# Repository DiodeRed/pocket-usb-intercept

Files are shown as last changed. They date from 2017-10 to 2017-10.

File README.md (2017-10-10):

# pocket-usb-intercept
A small mod board for the GDP Pocket to add a tiny internal USB hub for various purposes.

#### Bill of materials:

| Reference | Description | Part Number |
|---|---|---|
| U1 | 4-port USB 2.0 Hub IC | CY7C65632-28LTXC |
| Y1 | 12MHz Crystal | ABM10-166-12.000MHZ-T3 |
| R4 | 649 resistor (0603, 1%) | (generic) |
| R1,R3 | 10k resistor (0603, 1%) | (generic) |
| R2 | 47k resistor (0603, 1%) | (generic) |
| C3,C4 | 7pF capacitor (0603, 50V, NP0) | CGA3E2NP01H070D080AA |
| C5 | 1uF capacitor (0603, 25V, X7R) | CL10B105KA8NNNC |
| C1,C2 | 10uF capacitor (0805, 6.3V, X5R, low profile) | CL21A106MQCLNNC |
| P1,P2 | Flat Flex Connector | FH19C-10S-0.5SH |
| | 10pos 0.5mm pitch 4cm Flex Cable | 152660095 |
| | PCB (16mm x 13mm x 0.4mm) | |

---

<br />This work is licensed under a <a rel="license" href="http://creativecommons.org/licenses/by-sa/4.0/">Creative Commons Attribution-ShareAlike 4.0 International License</a>.

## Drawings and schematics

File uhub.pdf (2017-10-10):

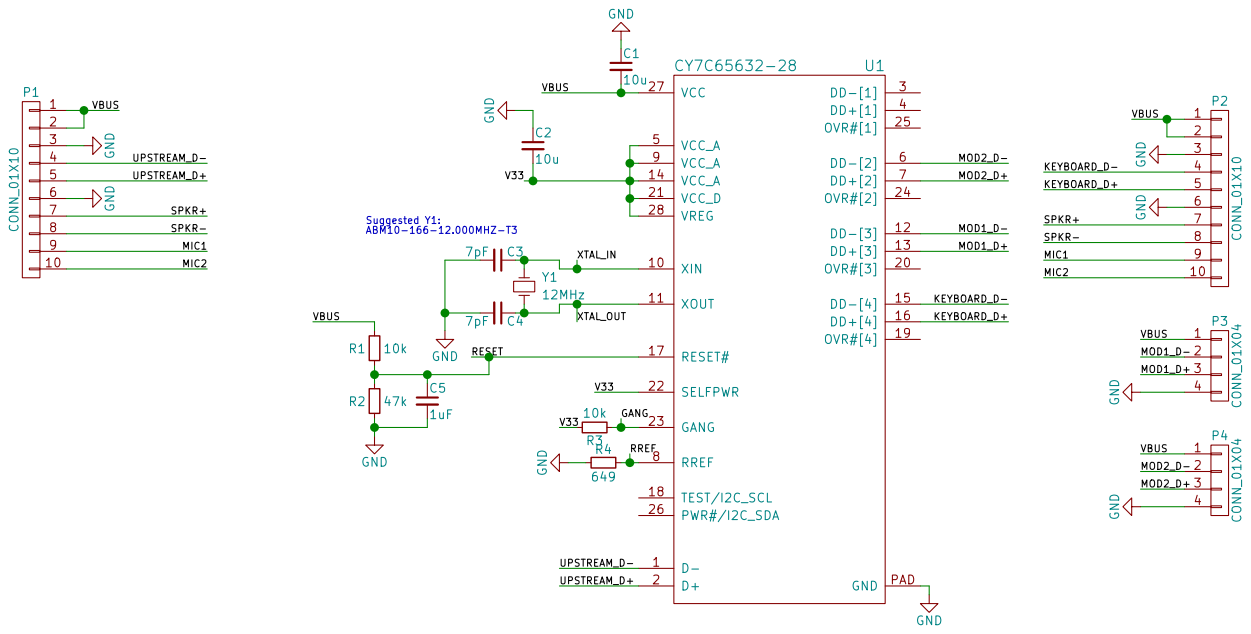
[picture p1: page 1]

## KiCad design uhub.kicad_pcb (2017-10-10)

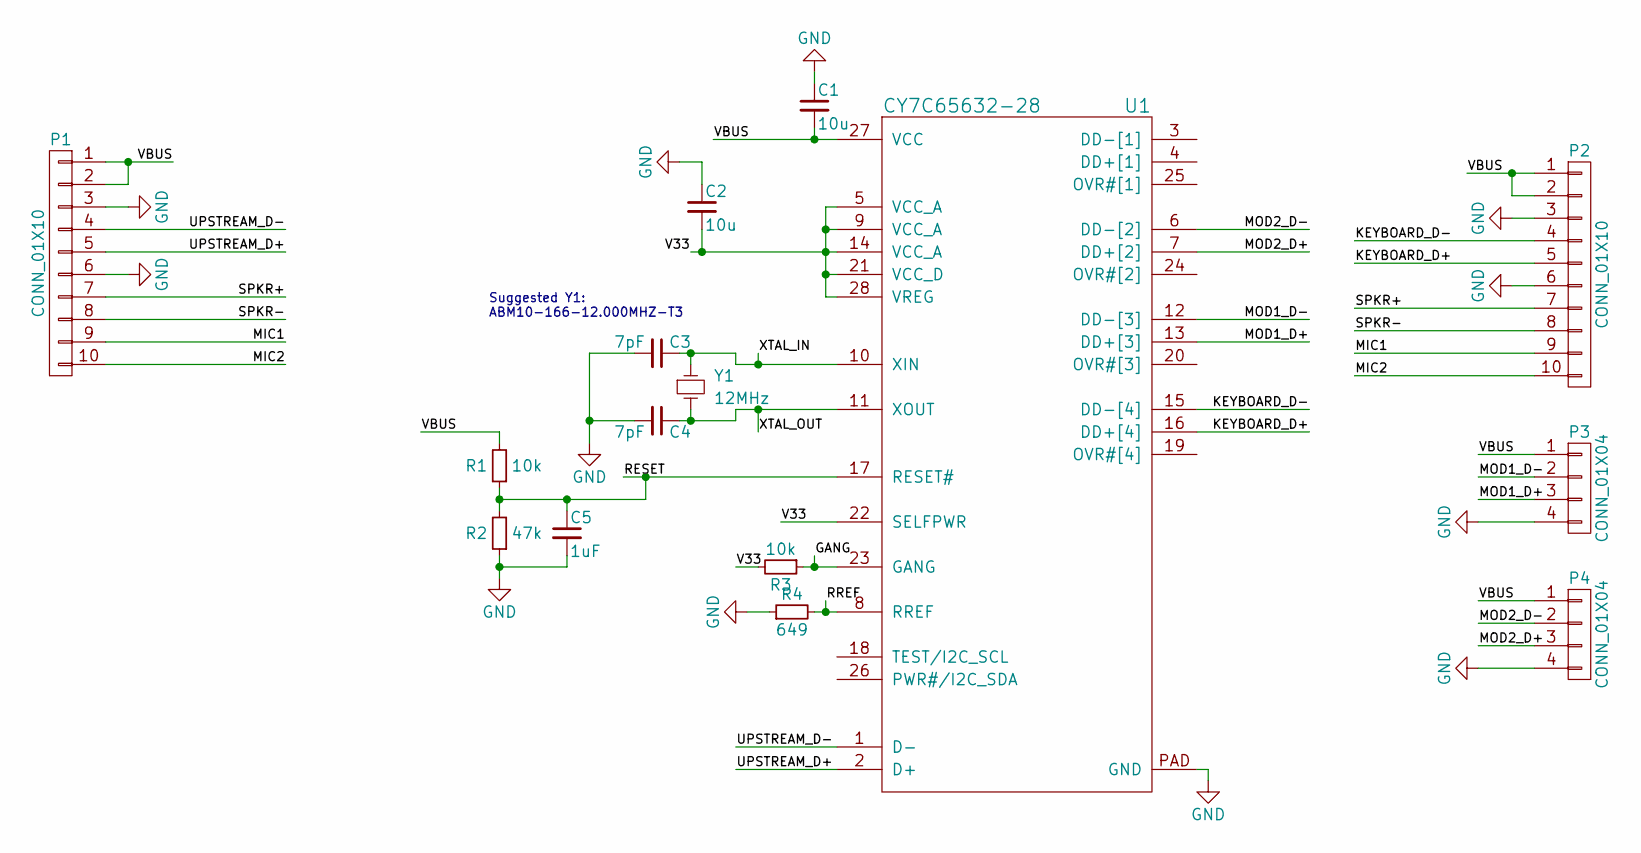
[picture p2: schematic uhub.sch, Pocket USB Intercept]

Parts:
C1, C2: 10u; C_0805
C3, C4: 7pF; C_0603
C5: 1uF; C_0603
P1: CONN_01X10; FH19C-10S-0.5SH
P2: CONN_01X10; FH19C-10S-0.5SH_REV
P3, P4: CONN_01X04; CONN-4-USB-TINY
R1, R3: 10k; R_0603
R2: 47k; R_0603
R4: 649; R_0603
U1: CY7C65632-28; QFN_28
Y1: 12MHz; ABM-XXX

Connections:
/GANG: R3.1, U1.23 (GANG)
/KEYBOARD_D+: P2.5, U1.16 (DD+[4])
/KEYBOARD_D-: P2.4, U1.15 (DD-[4])
/MIC1: P1.9, P2.9
/MIC2: P1.10, P2.10
/MOD1_D+: P3.3, U1.13 (DD+[3])
/MOD1_D-: P3.2, U1.12 (DD-[3])
/MOD2_D+: P4.3, U1.7 (DD+[2])
/MOD2_D-: P4.2, U1.6 (DD-[2])
/RESET: C5.1, R1.1, R2.2, U1.17 (RESET#)
/RREF: R4.2, U1.8 (RREF)
/SPKR+: P1.7, P2.7
/SPKR-: P1.8, P2.8
/UPSTREAM_D+: P1.5, U1.2 (D+)
/UPSTREAM_D-: P1.4, U1.1 (D-)
/V33: C2.2, R3.2, U1.5 (VCC_A), U1.9 (VCC_A), U1.14 (VCC_A), U1.21 (VCC_D), U1.22 (SELFPWR), U1.28 (VREG)
/VBUS: C1.2, P1.1, P1.2, P2.1, P2.2, P3.1, P4.1, R1.2, U1.27 (VCC)
/XTAL_IN: C3.1, U1.10 (XIN), Y1.1
/XTAL_OUT: C4.1, U1.11 (XOUT), Y1.2
GND: C1.1, C2.1, C3.2, C4.2, C5.2, P1.3, P1.6, P2.3, P2.6, P3.4, P4.4, R2.1, R4.1, U1.PAD (GND)

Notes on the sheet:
Suggested Y1: ABM10-166-12.000MHZ-T3

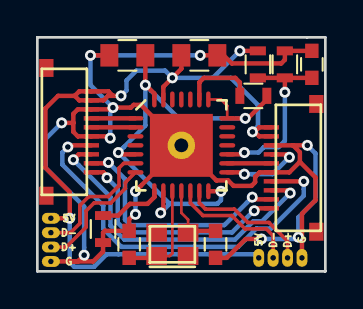
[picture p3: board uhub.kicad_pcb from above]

Board: 2 copper layers, 16.0 x 13.0 mm, 15 parts (0 on the bottom side), 20 nets.
